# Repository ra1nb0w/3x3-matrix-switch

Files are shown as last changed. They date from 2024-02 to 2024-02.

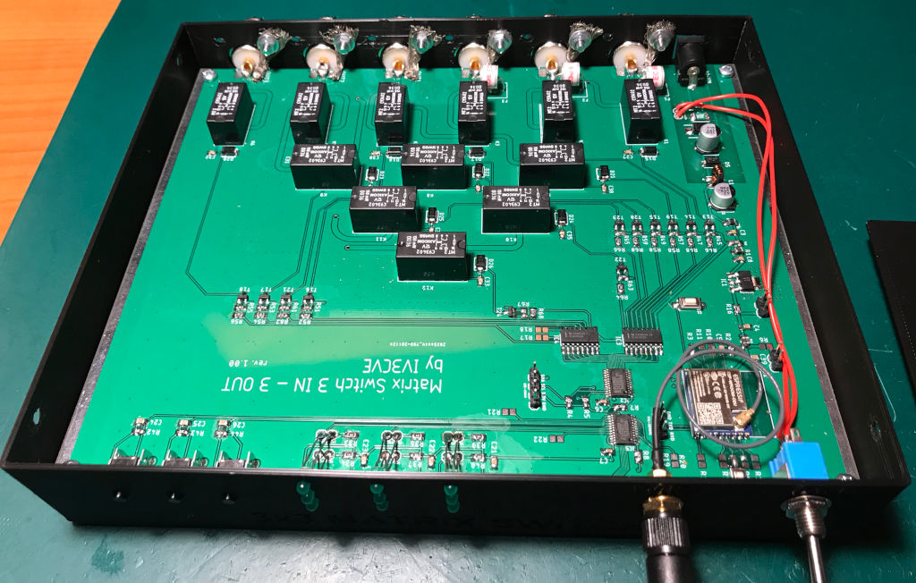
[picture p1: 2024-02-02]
matrix.jpg

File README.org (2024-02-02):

#+LANGUAGE:  en
#+STARTUP: showeverything

* 3x3 Matrix HF Switch

#+begin_html
<img src="matrix.jpg" alt="3x3 Matrix PCB and case" width="800">
#+end_html

The repository contains a project that I made in the 2020 after I was
frustrated to switch cables between radios and loads (antennas or
resistive load). It is a three by three matrix switch and it is mainly
designed for HF frequencies since it is a two layer PCB. In essence,
you can connect each of the three inputs to each of the three outputs
using a web interface (they are mutually exclusive). The web interface
permits to define a name for each port and it stores the connections.

** Folders

- *pcb*: contains the schematics, the BOM and the Gebers RS-274X;
- *case*: contains the two part of the 3D case that I use;
- *fw*: contains the firmware to load into the ESP8266. It uses the
  Arduino Framework and PlatformIO to manage the project. Read the
  README in the folder for more information.

** License

The project is licensed under [[https://creativecommons.org/licenses/by-nc-sa/4.0/][CC BY-NC-SA 4.0]]

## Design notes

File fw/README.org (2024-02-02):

* Firmware for the ESP8266 board

- the project uses PlatformIO as configuration/build tool
- copy include/wifi.h.example to include/wifi.h and set your WPA SSID and password
- when you write the firmware you also need to copy the data partition.
  If you don't change the data/ folder it is required only once.

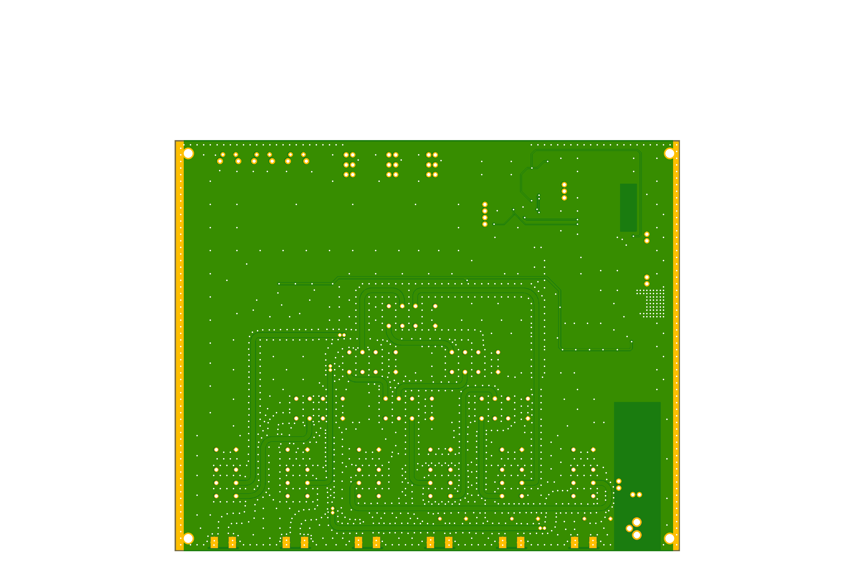
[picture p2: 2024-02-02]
pcb/back.png

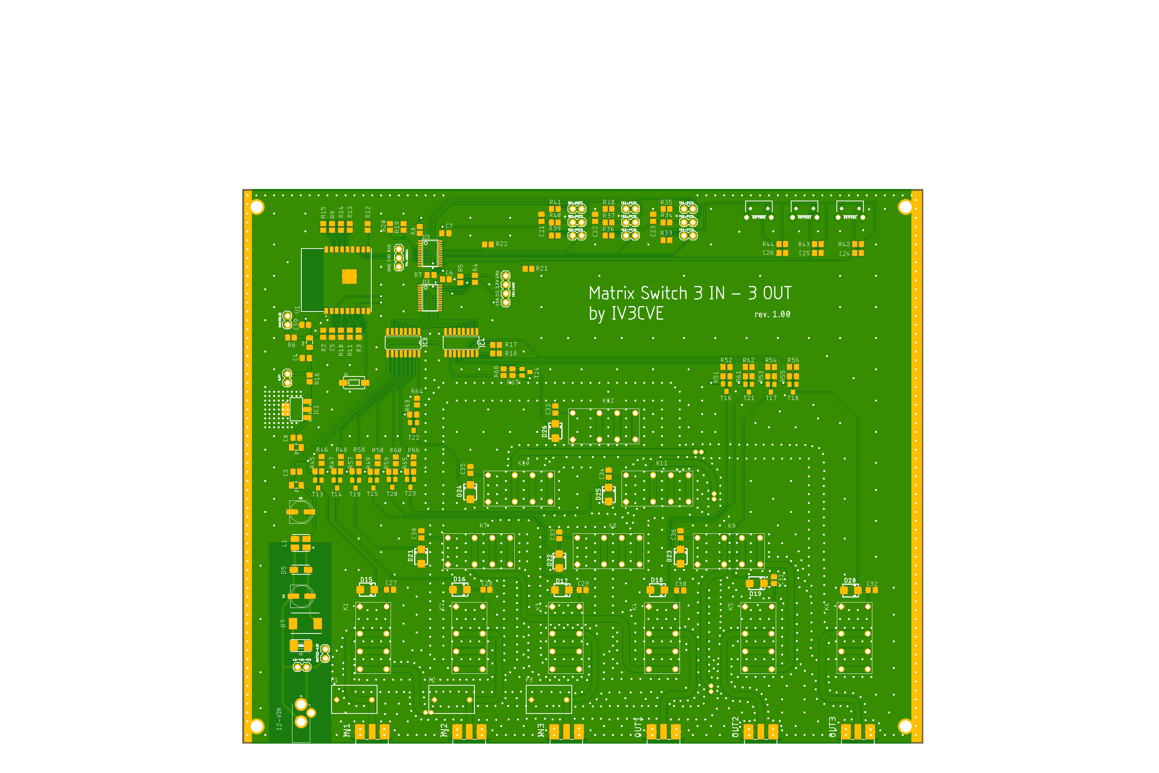
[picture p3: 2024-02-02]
pcb/front.png

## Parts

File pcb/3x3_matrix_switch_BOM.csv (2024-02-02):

Qty | Value | Device | Package | Parts | Description
12 |  | CONN_02 | 1X02 | 12-VIN-PIN, IN1-OUT1, IN1-OUT2, IN1-OUT3, IN2-OUT1, IN2-OUT2, IN2-OUT3, IN3-OUT1, IN3-OUT2, IN3-OUT3, POWERLED, SWITCH-12V | Multi connection point. Often used as Generic Header-pin footprint for 0.1 inch spaced/style header connections
1 | 0 | R-EU_R0805 | R0805 | R16 | RESISTOR, European symbol
10 | 0.1uF | C-EUC0805 | C0805 | C3, C5, C8, C21, C22, C23, C24, C25, C26, C39 | CAPACITOR, European symbol
2 | 100nF | C-EUC0805 | C0805 | C6, C7 | CAPACITOR, European symbol
21 | 10k | R-EU_R0805 | R0805 | R2, R3, R4, R5, R7, R8, R42, R43, R44, R45, R47, R49, R51, R53, R55, R57, R59, R61, R63, R65, R67 | RESISTOR, European symbol
12 | 10nF | C-EUC0805 | C0805 | C27, C28, C29, C30, C31, C32, C33, C34, C35, C36, C37, C38 | CAPACITOR, European symbol
1 | 1613_20 | 1613_20 | 161320 | 12-VIN | LUMBERG - 1613 20 - SOCKET, DC, 90DEG, PCB MOUNT
1 | 1812L110/24 | PTCFUSE-1812 | 1812 | F5 | PTC fuses, resettable thermistors
1 | 3.3V | CONN_02 | 1X02 | 3.3V | Multi connection point. Often used as Generic Header-pin footprint for 0.1 inch spaced/style header connections
12 | 3.3k | R-EU_R0805 | R0805 | R46, R48, R50, R52, R54, R56, R58, R60, R62, R64, R66, R68 | RESISTOR, European symbol
1 | 4.7uF | C-EUC0805 | C0805 | C4 | CAPACITOR, European symbol
1 | 455-1750-1-ND | CONN_03 | 1X03 | TTL-SERIAL | Multi connection point. Often used as Generic Header-pin footprint for 0.1 inch spaced/style header connections
1 | 455-1750-1-ND | CONN_04 | 1X04 | I2C-CONN | Multi connection point. Often used as Generic Header-pin footprint for 0.1 inch spaced/style header connections
2 | 470uF | 47UF-POLAR-PANASONIC_D-35V-20% | PANASONIC_D | C1, C2 | 47µF polarized capacitors
9 | 680 | R-EU_R0805 | R0805 | R33, R34, R35, R36, R37, R38, R39, R40, R41 | RESISTOR, European symbol
3 | B88069X0780S102 | 0259.125T | 0259.125T | F1, F2, F3 | FUSE BRD MNT 125MA 125VAC/VDC
12 | BC807-25L | BC807-25-PNP-SOT23-BEC | SOT23-BEC | T13, T14, T15, T16, T17, T18, T19, T20, T21, T22, T23, T24 | PNP Transistror
3 | BLM31PG601SN1L | BLM31PG601SN1L | BEADC3216X130N | FL1, FL2, FL3 | Ind Chip Bead 600Ohm 25% 100MHz Ferrite 1.5A 1206 Embossed T/R Check prices
14 | DNI | R-EU_R0805 | R0805 | R6, R9, R10, R11, R12, R13, R14, R15, R17, R18, R19, R20, R21, R22 | RESISTOR, European symbol
1 | ESP-WROOM-02U | ESP-WROOM-02D | MODULE_ESP-WROOM-02D | U1 | WiFi 802.11b/g/n Transceiver Module 2.4GHz ~ 2.5GHz Integrated, Trace Surface Mount
3 | EVQPF008K | MOMENTARY-SWITCH-SPST-PTH-RIGHT-ANGLE-KIT | TACTILE_SWITCH_PTH_RIGHT_ANGLE_KIT | BUTTON1, BUTTON2, BUTTON3 | Momentary Switch (Pushbutton) - SPST
2 | PCA9555PW | PCA9555PW | TSSOP24 | IC2, IC5 | 16-bit I2C and SMBus I/O port with interrupt
1 | RS032G05A3SM-SPST-MOMENTARY-SWSMD-1101NE | RS032G05A3SM-SPST-MOMENTARY-SWSMD-1101NE | TACTILE-SWITCH-1101NE | S1 | 6x3.5mm 2-pin Momentary Switch (Push-button)
12 | S1M | S1M | SMA | D15, D16, D17, D18, D19, D20, D21, D22, D23, D24, D25, D26
6 | SMA-142-0711-821/826 | SMA-142-0711-821/826 | J502-ND-142-0711-821/826 | IN1, IN2, IN3, OUT1, OUT2, OUT3 | SMA 50 Ohm End Launch Jack Receptacle - Round Contact
1 | SMAJ14A | SMAJ30A-E3_61 | DIOM5127X229N | D5 | Vishay SMAJ30A-E3/61, Uni-Directional TVS Diode, 400W, 2-Pin DO-214AC
1 | SRF0504-102Y | SRF0504-102Y | FIL_SRF0504-102Y | L1 | Common Mode Chokes Dual 600nH 190Ohm 100kHz 5A 20mOhm DCR SMD T/R Check prices
1 | SS26 | B540C-13-F | DIOM7959X250N | D7 | Diodes Inc B540C-13-F, SMT Schottky Diode, 40V 5A, 2-Pin DO-214AB
1 | UA78M33DCY | UA78M33DCY | SOT223 | IC1 | POSITIVE-VOLTAGE REGULATORS
2 | ULN2003AD | ULN2003AD | SO16 | IC3, IC4 | DRIVER ARRAY
12 | V23105A5403A201 | V23105A5403A201 | V23105A5307A201 | K1, K2, K3, K4, K5, K6, K7, K8, K9, K10, K11, K12 | RELAY, V23105A5403A201

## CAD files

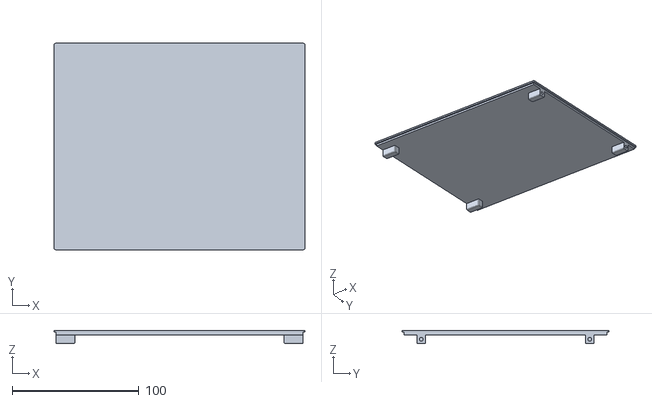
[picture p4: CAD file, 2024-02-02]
case/3x3_matrix_cover.stl
198.0 x 163.0 x 10.5

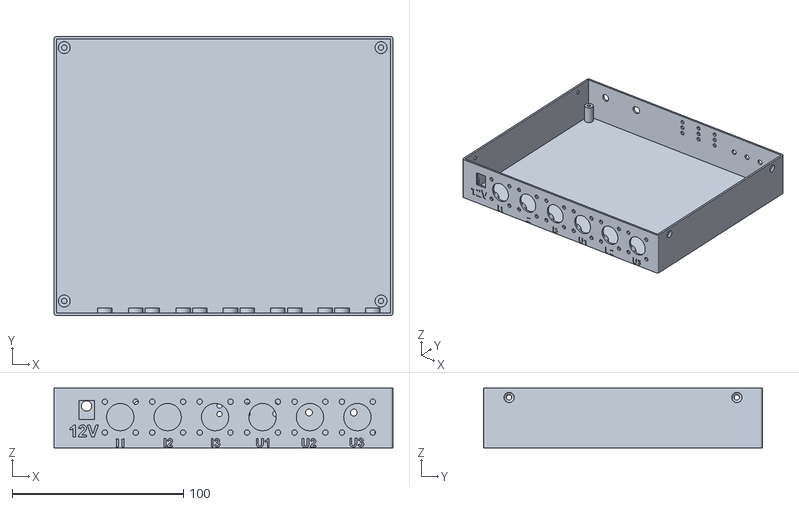
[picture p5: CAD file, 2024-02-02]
case/3x3_matrix_case.stl
198.0 x 163.0 x 35.0

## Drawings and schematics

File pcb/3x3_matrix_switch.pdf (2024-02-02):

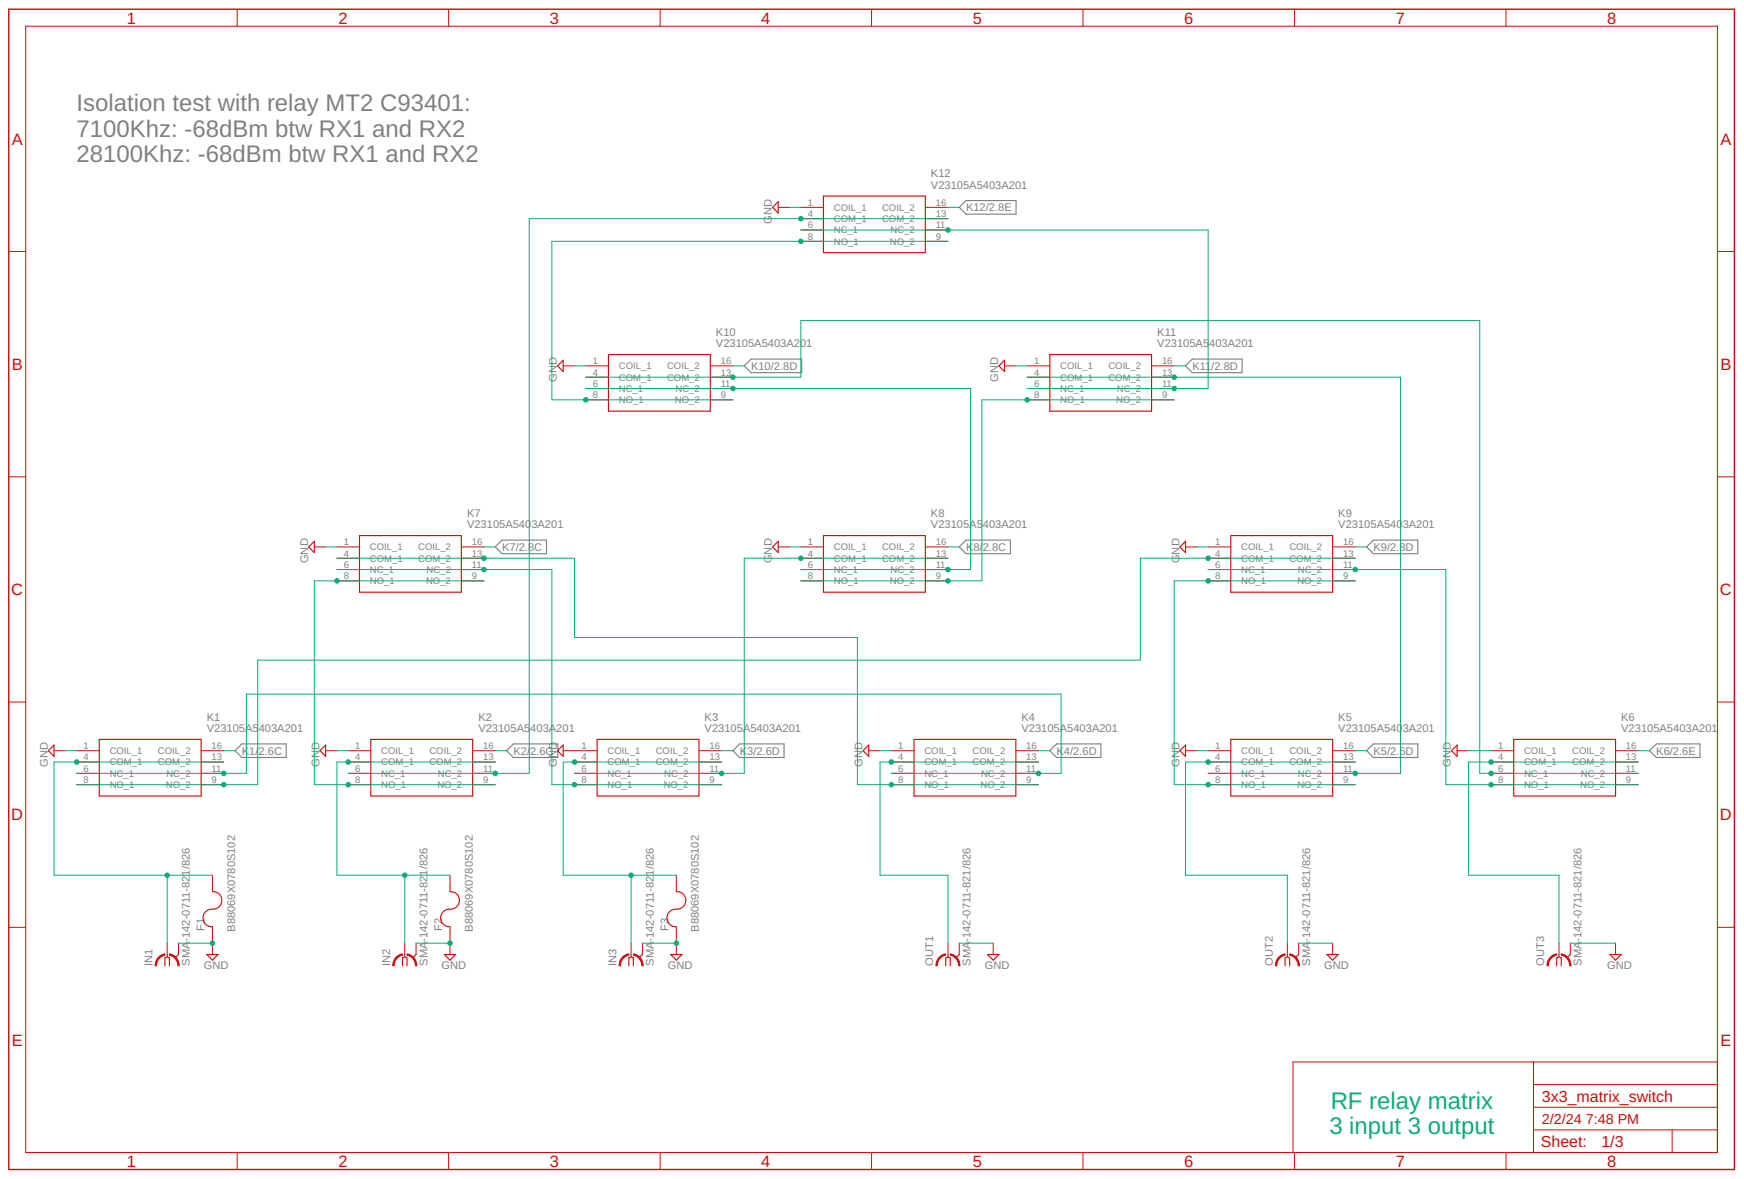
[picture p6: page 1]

Isolation test with relay MT2 C93401:
7100Khz: -68dBm btw RX1 and RX2
28100Khz: -68dBm btw RX1 and RX2

6 | NO_1 | 11 COM_2

RF relay matrix 3 input 3 output

Sheet: 1/3

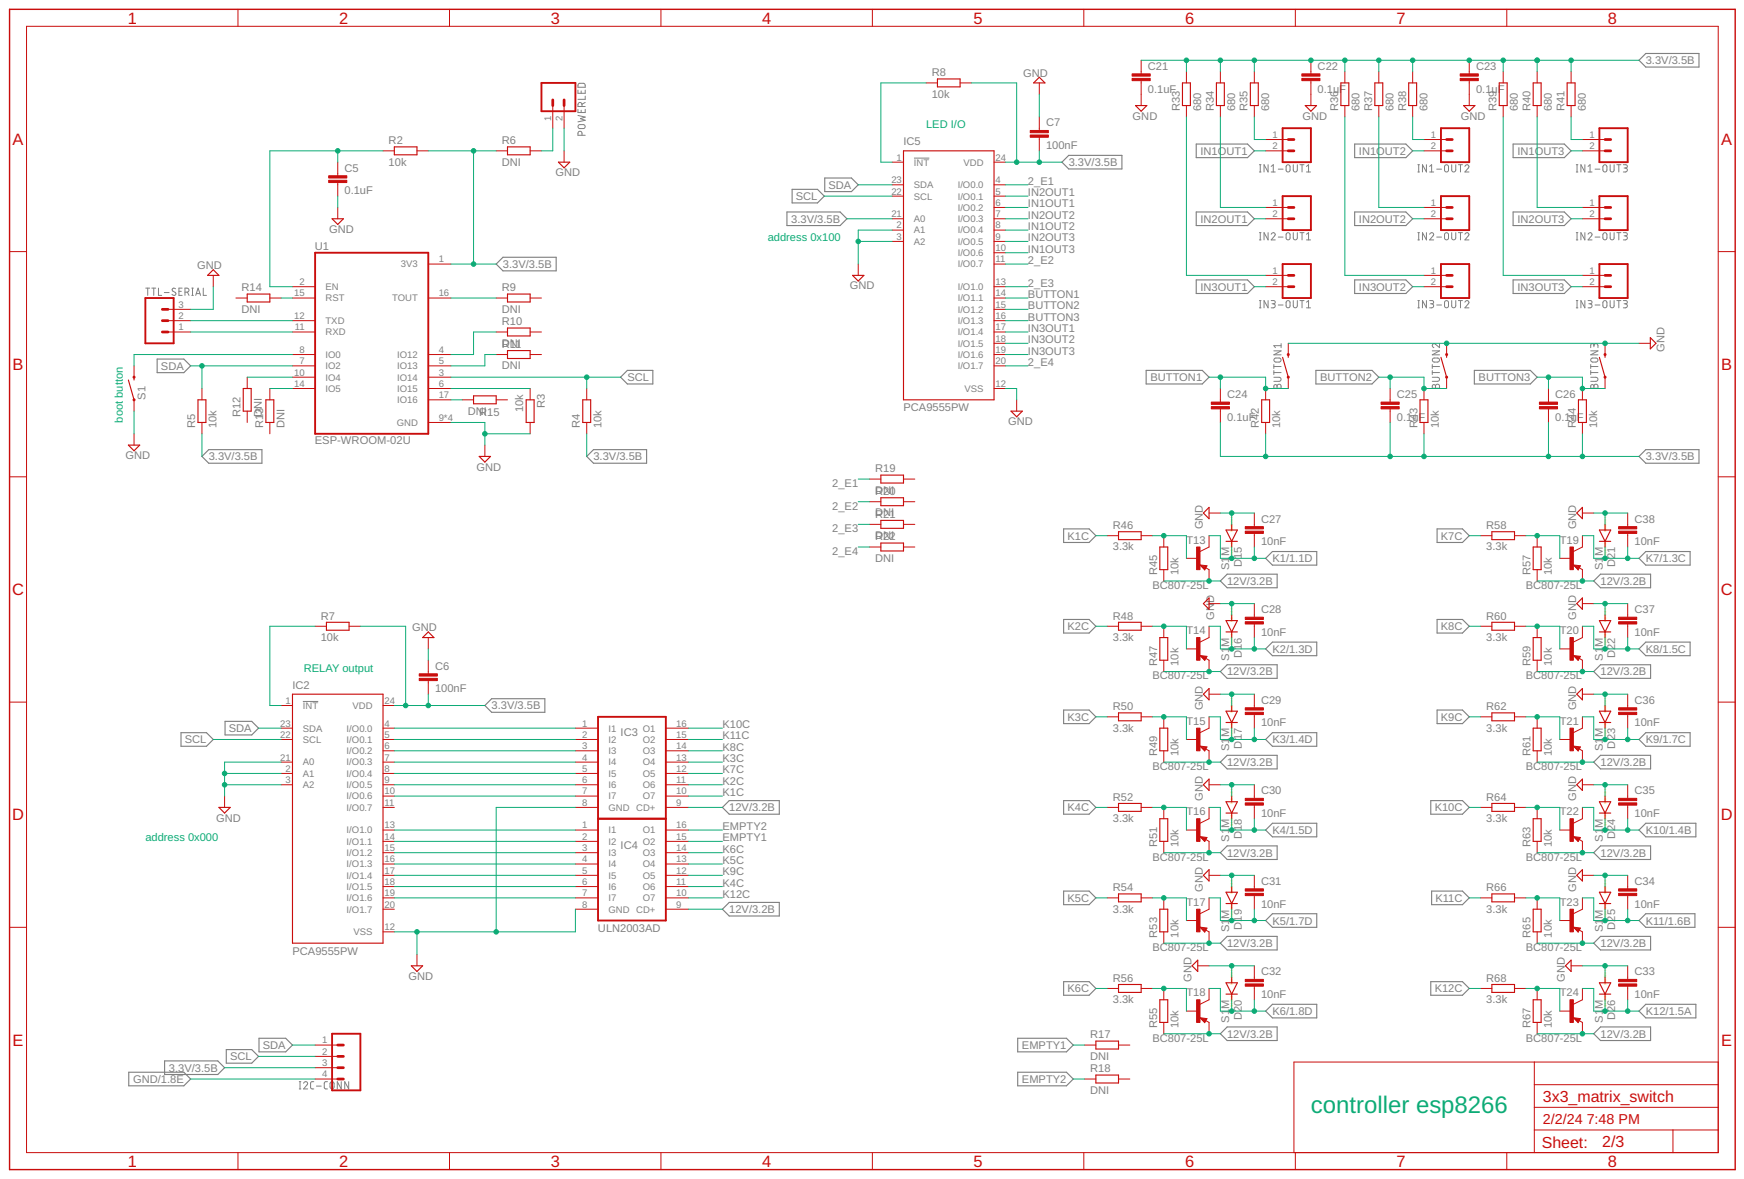
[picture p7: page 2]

SpiceOrder 1 SpiceOrder 2 SpiceOrder 1 SpiceOrder 2 SpiceOrder 1 SpiceOrder 2

14 | 2
15 | 3
16 | 4
17 | 5
18 | 6

controller esp8266

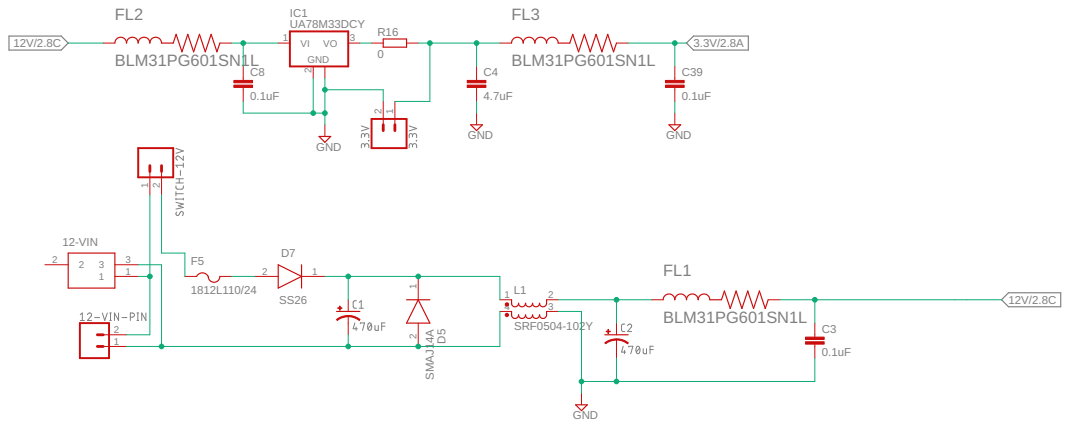
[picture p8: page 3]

power supply IN: 12-13.8V OUT: 3.3V

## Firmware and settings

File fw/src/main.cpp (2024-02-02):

/**
 * NOTE:
 *  in many parts is strictly implemented for 3x3 in/out ports
 *  therefore you should probably rewrite the webserver part
 *  and the index.html to use cycles to scan all values if you
 *  need more ports
 */



#include "Wire.h"
#include <ESP8266WiFi.h>
#include <ArduinoOTA.h>
#include "basicOTA.h"
#include "webserver.h"
#include "ports.h"
#include "config.h"
#include "wifi.h"


void setup() {

  Serial.begin(9600);
  while (!Serial);

  ports.init();
  ports.initialize_leds();
  ports.leds_enable();
  ports.initialize_buttons();
  ports.initialize_relays();

  //Initialize File System
  SPIFFS.begin();
  Serial.println("File System Initialized");

  //Begin WiFi
  WiFi.mode(WIFI_STA);
  WiFi.begin(WIFI_SSID, WIFI_PASS);

  // set hostname
  WiFi.hostname("3x3-matrix");

  // Connecting to WiFi...
  Serial.print("Connecting to ");
  Serial.print(WIFI_SSID);
  // Loop continuously while WiFi is not connected
  while (WiFi.status() != WL_CONNECTED)
  {
    delay(100);
    Serial.print(".");
  }
  
  // Connected to WiFi
  Serial.println();
  Serial.print("Connected! IP address: ");
  Serial.println(WiFi.localIP());

  // enable light sleep mode
  WiFi.setSleepMode(WIFI_LIGHT_SLEEP);

  // Setup Firmware update over the air (OTA)
  setup_OTA();

  // initialize web server
  webserver.init();

  // disable all leds when everything is up
  ports.leds_disable();

  // configure the routing
  ports.make_routing();
}

void loop() {

  // Check for OTA updates
  ArduinoOTA.handle();

  // handle request from client
  webserver.handleClient();

  // can we use interrupt?
  ports.check_buttons();

}

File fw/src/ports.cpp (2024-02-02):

#include "ports.h"

// Object to manage the ports
PCA9555 ioport1(0x20); // relay expander
PCA9555 ioport2(0x21); // leds and buttons expander


Ports::Ports()
{
    EEPROM.begin(512);  //Initialize EEPROM

    // default input-output path
    switch_connection[0] = 0; // dummy

    // default
    pressed_button = 0;
    next_flip = 0;

    // define the path
    memset(routing, 0, sizeof(routing));

    // 1 -> 1 OFF(K1, K4)
    routing[1][1] = { .step = 0, .relay = {0}, .led = 1};
    // 1 -> 2 ON(K1, K9, K5)
    routing[1][2] = { .step = 3, .relay = {1, 9, 5}, .led = 2};
    // 1 -> 3 ON(K1, K6) OFF(K9)
    routing[1][3] = { .step = 2, .relay = {1, 6}, .led = 3};

    // 2 -> 1 ON(K2, K7, K4)
    routing[2][1] = { .step = 3, .relay = {2, 7, 4}, .led = 4};
    // 2 -> 2 OFF(K2, K12, K11, K5)
    routing[2][2] = { .step = 0, .relay = {0}, .led = 5};
    // 2 -> 3 OFF(K2, K6) ON(K12, K10)
    routing[2][3] = { .step = 2, .relay = {12, 10}, .led = 6};

    // 3 -> 1 ON(K3, K4) OFF(K7)
    routing[3][1] = { .step = 2, .relay = {3, 4}, .led = 7};
    // 3 -> 2 OFF(K3, K5) ON(K8, K11)
    routing[3][2] = { .step = 2, .relay = {8, 11}, .led = 8};
    // 3 -> 3 OFF(K3, K8, K10, K6)
    routing[3][3] = { .step = 0, .relay = {0}, .led = 9};

    memset(in_port_name, '\0', sizeof(in_port_name));
    memset(out_port_name, '\0', sizeof(out_port_name));
}

Ports::~Ports()
{
}

void Ports::init()
{
    // initialiaze the pca9555 ports
    ioport1.begin();
    ioport2.begin();

    // sets the I2C clock to 400kHz
    ioport1.setClock(400000);
    ioport2.setClock(400000);

    // load stored routing from the EEPROM
    load_routes();

    // load ports name
    load_port_name();
}


void Ports::initialize_leds()
{
    uint8_t i;
    // configure the led ports
    for (i=0; i < sizeof(led_pinout); i++) {
        ioport2.pinMode(led_pinout[i], OUTPUT);
    }
}

void Ports::leds_enable()
{
    uint8_t i;
    for (i=0; i < sizeof(led_pinout); i++) {
        ioport2.digitalWrite(led_pinout[i], LOW);
    }
}

void Ports::leds_disable()
{
    uint8_t i;
    for (i=0; i < sizeof(led_pinout); i++) {
        ioport2.digitalWrite(led_pinout[i], HIGH);
    }
}

void Ports::initialize_buttons()
{
    uint8_t i;
    for (i=0; i < sizeof(button_pinout); i++) {
      ioport2.pinMode(button_pinout[i], INPUT);
     }
}

void Ports::initialize_relays()
{
    uint8_t i;
    for (i=0; i < sizeof(relay_pinout); i++) {
        ioport1.pinMode(relay_pinout[i], OUTPUT);
     }
}

void Ports::relays_enable()
{
    uint8_t i;
    for (i=0; i < sizeof(relay_pinout); i++) {
        ioport1.digitalWrite(relay_pinout[i], HIGH);
    }
}

void Ports::relays_disable()
{
    uint8_t i;
    for (i=0; i < sizeof(relay_pinout); i++) {
        ioport1.digitalWrite(relay_pinout[i], LOW);
    }
}

// configure the relays based on the
// lookup table and the configuration
void Ports::make_routing()
{
    // disable all led before enable it
    leds_disable();

    // reset all ports to the default status
    relays_disable();

    uint8_t input_port;
    uint8_t tmp_r;
    path tmp_path;
    for(input_port=1; input_port <= INPUT_PORTS; input_port++)
    {
        tmp_path = routing[input_port][switch_connection[input_port]];

        // power on the right led
        for (tmp_r = 0; tmp_r < tmp_path.step; tmp_r++) {
            ioport1.digitalWrite(relay_pinout[tmp_path.relay[tmp_r]], HIGH);
        }

        // power on the right led
        ioport2.digitalWrite(led_pinout[tmp_path.led], LOW);
    }
}

void Ports::check_buttons()
{
    uint8_t i;
    
    if (pressed_button != 0) {
        if (ioport2.digitalRead(button_pinout[pressed_button]) == HIGH)
           pressed_button = 0;  // reset the status
    } else {
        // check if there is a press
        for (i=1; i <= BUTTON_NUMBER; i++) {
           if (ioport2.digitalRead(button_pinout[i]) == LOW) {
               DEBUG("Button ");
               DEBUG(i);
               DEBUGLN(" is pressed");
               pressed_button = i;
               change_next_route(pressed_button);
           }
        }
    }

    // just a bit of delay
    delay(10);
}

// Manage the buttons changing the routing incrementally
void Ports::change_next_route(uint8_t input)
{
    uint8_t tmp, next, next2;

    next = input+1 > INPUT_PORTS ? 1 : input+1;
    next2 = input+2 > INPUT_PORTS ? (input == 2 ? 1 : 2) : input+2;

    if (next_flip && old_button == input) {
        tmp = switch_connection[input];
        switch_connection[input] = switch_connection[next];
        switch_connection[next] = tmp;
        next_flip = 0;
    } else {
        tmp = switch_connection[next];
        switch_connection[next] = switch_connection[next2];
        switch_connection[next2] = tmp;
        next_flip = 1;
        old_button = input;
    }

    DEBUG("Button pressed; move to ports: 1=");
    DEBUG(switch_connection[1]);
    DEBUG(" 2=");
    DEBUG(switch_connection[2]);
    DEBUG(" 3=");
    DEBUGLN(switch_connection[3]);

    make_routing();

    // when we press the buttons
    // we always store the new configuration
    store_routes();
}

// maybe use an array to be easily scalable
void Ports::set_inout(uint8_t in1_out, uint8_t in2_out, uint8_t in3_out, uint8_t save)
{
    // just to avoid useless cycles
    if (switch_connection[1] == in1_out &&
        switch_connection[2] == in2_out &&
        switch_connection[3] == in3_out &&
        save == 0)
        return;

    switch_connection[1] = in1_out > OUTPUT_PORTS ? 1 : in1_out;
    switch_connection[2] = in2_out > OUTPUT_PORTS ? 2 : in2_out;
    switch_connection[3] = in3_out > OUTPUT_PORTS ? 3 : in3_out;

    // check if we need to save
    if (save == 1) {
        store_routes();
    }

    make_routing();
}

void Ports::store_routes()
{
    EEPROM.write(EEPROM_IN1_ADDR, switch_connection[1]);
    EEPROM.write(EEPROM_IN2_ADDR, switch_connection[2]);
    EEPROM.write(EEPROM_IN3_ADDR, switch_connection[3]);
    EEPROM.commit();
}

void Ports::load_routes()
{
    // check if have good values stored
    if (EEPROM.read(EEPROM_CANARY_ADDR) != EEPROM_CANARY_VALUE) {
        EEPROM.write(EEPROM_CANARY_ADDR, EEPROM_CANARY_VALUE);
        DEBUGLN("Initialize EEPROM for switch connection");
        // default input-output path
        switch_connection[1] = 1;
        switch_connection[2] = 2;
        switch_connection[3] = 3;
        store_routes();
    }

    switch_connection[1] = EEPROM.read(EEPROM_IN1_ADDR);
    switch_connection[2] = EEPROM.read(EEPROM_IN2_ADDR);
    switch_connection[3] = EEPROM.read(EEPROM_IN3_ADDR);
}
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
